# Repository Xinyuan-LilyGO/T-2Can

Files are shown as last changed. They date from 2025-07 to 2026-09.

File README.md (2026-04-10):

<!--
 * @Description: None
 * @Author: LILYGO_L
 * @Date: 2023-09-11 16:13:14
 * @LastEditTime: 2026-04-10 15:54:21
 * @License: GPL 3.0
-->
<h1 align = "center">T-2Can</h1>

## **English | [中文](./README_CN.md)**

## VersionIteration:
| Version | Update date |Update description|
| :---: | :---: |:---: |
| T-2Can_V1.0 | 2025-07-07 | Original version |
| T-2Can-Fd_V1.0 | 2026-04-10 | Can fd version |

## PurchaseLink

| Product | SOC |  FLASH  |  PSRAM | Link |
| :---: | :---: |:---: | :---: | :---: |
| T-2Can_V1.0 | NULL | NULL | NULL |  [LILYGO Mall](https://lilygo.cc/products/t-2can?_pos=1&_sid=a2c4b89a1&_ss=r&variant=51355687583925) |
| T-2Can-Fd_V1.0 | NULL | NULL | NULL |  [NULL]() |

## Directory
- [Describe](#describe)
- [Preview](#preview)
- [Module](#module)
- [SoftwareDeployment](#SoftwareDeployment)
- [PinOverview](#pinoverview)
- [RelatedTests](#RelatedTests)
- [FAQ](#faq)
- [Project](#project)

## Describe

The T-2Can is a board developed based on the ESP32-S3 chip and features two CAN buses. The T-2Can-Fd is the FD version of the T-2Can, adding CAN FD functionality. The CAN module used on the T-2Can is the MCP2515, while the CAN module used on the T-2Can-Fd is the MCP2518.

## Preview

### Actual Product Image

## Module

### 1. Core Processor  

* Module: ESP32-S3-WROOM-1U（MCN16R8）
* Related documentation: 
    >[Espressif](https://www.espressif.com/en/support/documents/technical-documents)
    
### 2. CAN chip

> #### T-2Can_V1.0 version
> * Chip: MCP2515
> * Communication Protocol: Spi
> * Related documentation: 
>    >[MCP2515T-E-SO](./information/MCP2515T-E-SO.pdf)
> * Dependent libraries: 
>    >[arduino-mcp2515](https://github.com/autowp/arduino-mcp2515)

> #### T-2Can-Fd_V1.0 version
> * Chip: MCP2518
> * Communication Protocol: Spi
> * Related documentation: 
>    >[MCP2518FDT-E-SL](./information/MCP2518FDT-E-SL.pdf)
> * Dependent libraries: 
>    >[Longan_CANFD](https://github.com/Longan-Labs/Longan_CANFD)

## SoftwareDeployment

### Examples Support

| Example | `[Platformio IDE][espressif32-v6.5.0]`<br />`[Arduino IDE][esp32_v2.0.14]` | Description | Picture |
| ---  | --- | --- | --- |
| [can](./examples/can) |  <p align="center"> | | |
| [original_test](./examples/original_test) |  <p align="center"> | factory example | |

[supported]: https://img.shields.io/badge/-supported-green "example"

| Firmware | Description | Picture |
| ---  | ---  | --- |
| [original_test](./firmware/[T-2Can_V1.0][original_test]_firmware/) | factory example  |  |
| [original_test (can fd)](./firmware/[T-2Can-Fd_V1.0][original_test]_firmware/) | can fd factory example  |  |

### PlatformIO
1. Install [VisualStudioCode](https://code.visualstudio.com/Download) ,Choose installation based on your system type.

2. Open the "Extension" section of the Visual Studio Code software sidebar(Alternatively, use "<kbd>Ctrl</kbd>+<kbd>Shift</kbd>+<kbd>X</kbd>" to open the extension),Search for the "PlatformIO IDE" extension and download it.

3. During the installation of the extension, you can go to GitHub to download the program. You can download the main branch by clicking on the "<> Code" with green text, or you can download the program versions from the "Releases" section in the sidebar.

4. After the installation of the extension is completed, open the Explorer in the sidebar(Alternatively, use "<kbd>Ctrl</kbd>+<kbd>Shift</kbd>+<kbd>E</kbd>" go open it),Click on "Open Folder," locate the project code you just downloaded (the entire folder), and click "Add." At this point, the project files will be added to your workspace.

5. Open the "platformio.ini" file in the project folder (PlatformIO will automatically open the "platformio.ini" file corresponding to the added folder). Under the "[platformio]" section, uncomment and select the example program you want to burn (it should start with "default_envs = xxx") Then click "<kbd>[√](image/4.png)</kbd>" in the bottom left corner to compile,If the compilation is correct, connect the microcontroller to the computer and click "<kbd>[→](image/5.png)</kbd>" in the bottom left corner to download the program.

### Arduino
1. Install [Arduino](https://www.arduino.cc/en/software) ,Choose installation based on your system type.

2. Open the "example" directory within the project folder, select the example project folder, and open the file ending with ".ino" to open the Arduino IDE project workspace.

3. Open the "Tools" menu at the top right -> Select "Board" -> "Board Manager." Find or search for "esp32" and download the board files from the author named "Espressif Systems." Then, go back to the "Board" menu and select the development board type under "ESP32 Arduino." The selected development board type should match the one specified in the "platformio.ini" file under the [env] section with the header "board = xxx." If there is no corresponding development board, you may need to manually add the development board from the "board" directory within your project folder.

4. Open menu bar "[File](image/6.png)" -> "[Preferences](image/6.png)" ,Find "[Sketchbook location](image/7.png)"  here,copy and paste all library files and folders from the "libraries" folder in the project directory into the "libraries" folder in this directory.

5. Select the correct settings in the Tools menu, as shown in the table below.

#### ESP32-S3
| Setting | Value |
| :---: | :---: |
| Board | ESP32S3 Dev Module |
| Upload Speed | 921600 |
| USB Mode | Hardware CDC and JTAG |
| USB CDC On Boot | Enabled |
| USB Firmware MSC On Boot | Disabled |
| USB DFU On Boot | Disabled |
| CPU Frequency | 240MHz (WiFi) |
| Flash Mode | QIO 80MHz |
| Flash Size | 16MB (128Mb) |
| Core Debug Level | None |
| Partition Scheme | 16M Flash (3MB APP/9.9MB FATFS) |
| PSRAM | OPI PSRAM |
| Arduino Runs On | Core 1 |
| Events Run On | Core 1 | 

6. Select the correct port.

7. Click "<kbd>[√](image/8.png)</kbd>" in the upper right corner to compile,If the compilation is correct, connect the microcontroller to the computer,Click "<kbd>[→](image/9.png)</kbd>" in the upper right corner to download.

### firmware download
1. Open the project file "tools" and locate the ESP32 burning tool. Open it.

2. Select the correct burning chip and burning method, then click "OK." As shown in the picture, follow steps 1->2->3->4->5 to burn the program. If the burning is not successful, press and hold the "BOOT-0" button and then download and burn again.

3. Burn the file in the root directory of the project file "[firmware](./firmware/)" file,There is a description of the firmware file version inside, just choose the appropriate version to download.

<p align="center" width="100%">
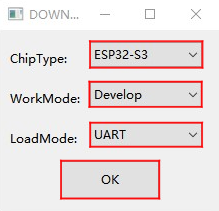
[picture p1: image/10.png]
    
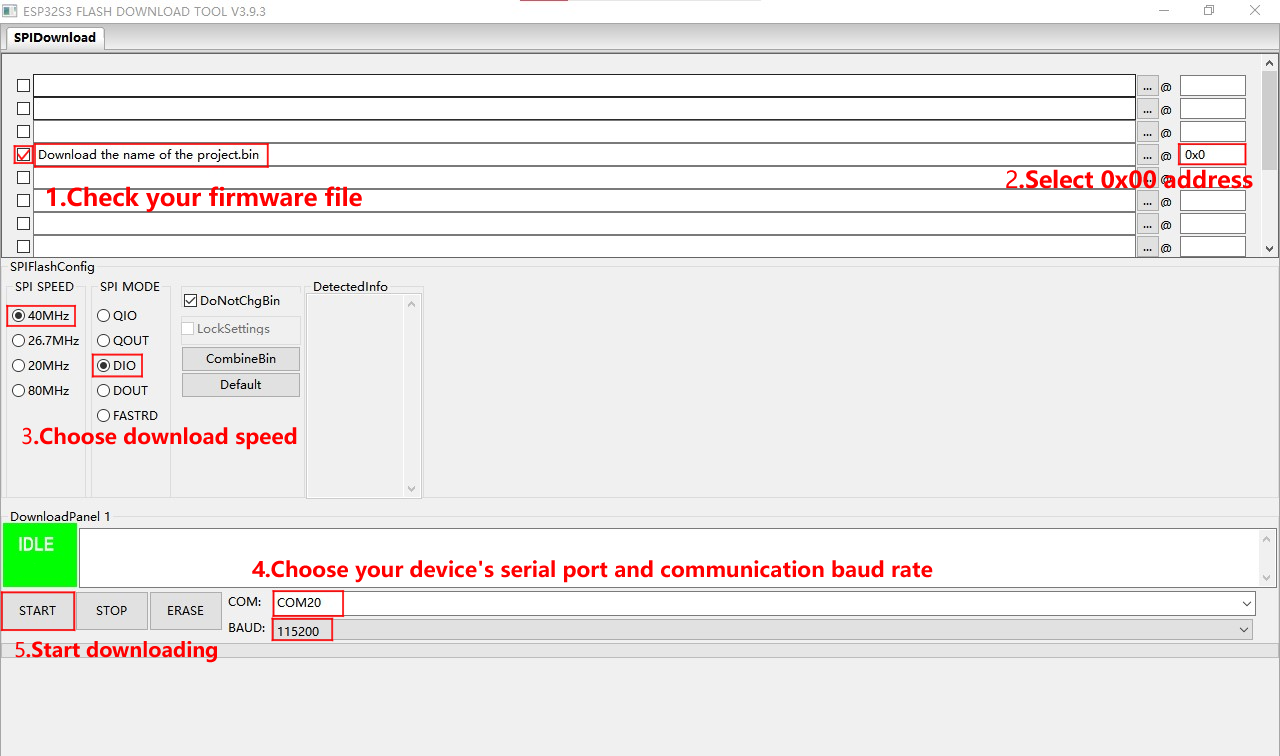
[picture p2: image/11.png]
    
</p>

## PinOverview

For pin definitions, please refer to the configuration file: [pin_config.h](./libraries/private_library/pin_config.h)

## RelatedTests

## FAQ

* Q. After reading the above tutorials, I still don't know how to build a programming environment. What should I do?
* A. If you still don't understand how to build an environment after reading the above tutorials, you can refer to the [LilyGo-Document](https://github.com/Xinyuan-LilyGO/LilyGo-Document) document instructions to build it.

<br />

* Q. Why does Arduino IDE prompt me to update library files when I open it? Should I update them or not?
* A. Choose not to update library files. Different versions of library files may not be mutually compatible, so it is not recommended to update library files.

<br />

* Q. Why is there no serial data output on the "Uart" interface on my board? Is it defective and unusable?
* A. The default project configuration uses the USB interface as Uart0 serial output for debugging purposes. The "Uart" interface is connected to Uart0, so it won't output any data without configuration.<br />For PlatformIO users, please open the project file "platformio.ini" and modify the option under "build_flags = xxx" from "-D ARDUINO_USB_CDC_ON_BOOT=true" to "-D ARDUINO_USB_CDC_ON_BOOT=false" to enable external "Uart" interface.<br />For Arduino users, open the "Tools" menu and select "USB CDC On Boot: Disabled" to enable the external "Uart" interface.

<br />

* Q. Why is my board continuously failing to download the program?
* A. Please hold down the "BOOT-0" button and try downloading the program again.

## Project
* [T-2Can_V1.0](./project/T-2Can_V1.0.pdf)
* [T-2Can-Fd_V1.0](./project/T-2Can-Fd_V1.0.pdf)

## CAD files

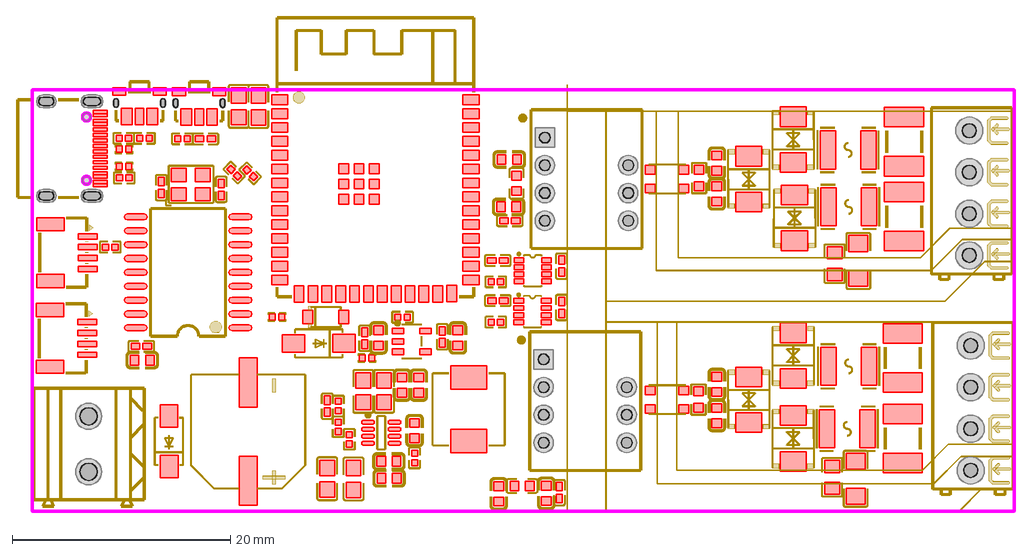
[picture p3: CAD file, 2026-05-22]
structure/T-2Can_Top_AutoCAD2007_202605221644.dxf
91.5 x 45.4 mm

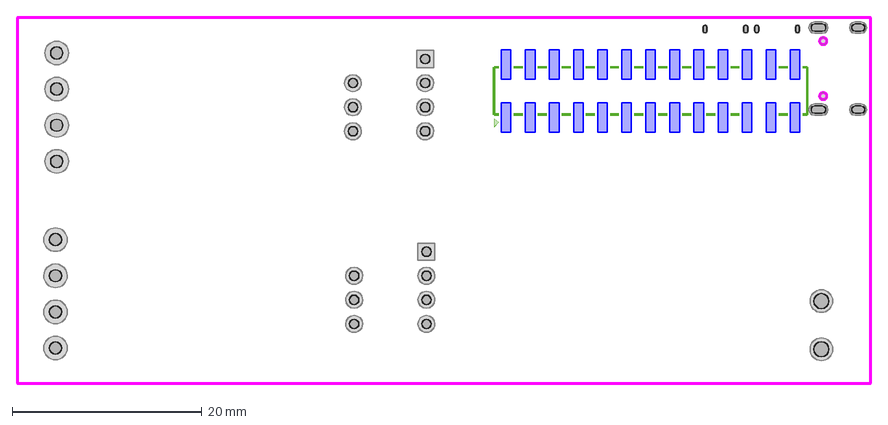
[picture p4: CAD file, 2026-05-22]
structure/T-2Can_Bot_AutoCAD2007_202605221644.dxf
90.2 x 38.8 mm

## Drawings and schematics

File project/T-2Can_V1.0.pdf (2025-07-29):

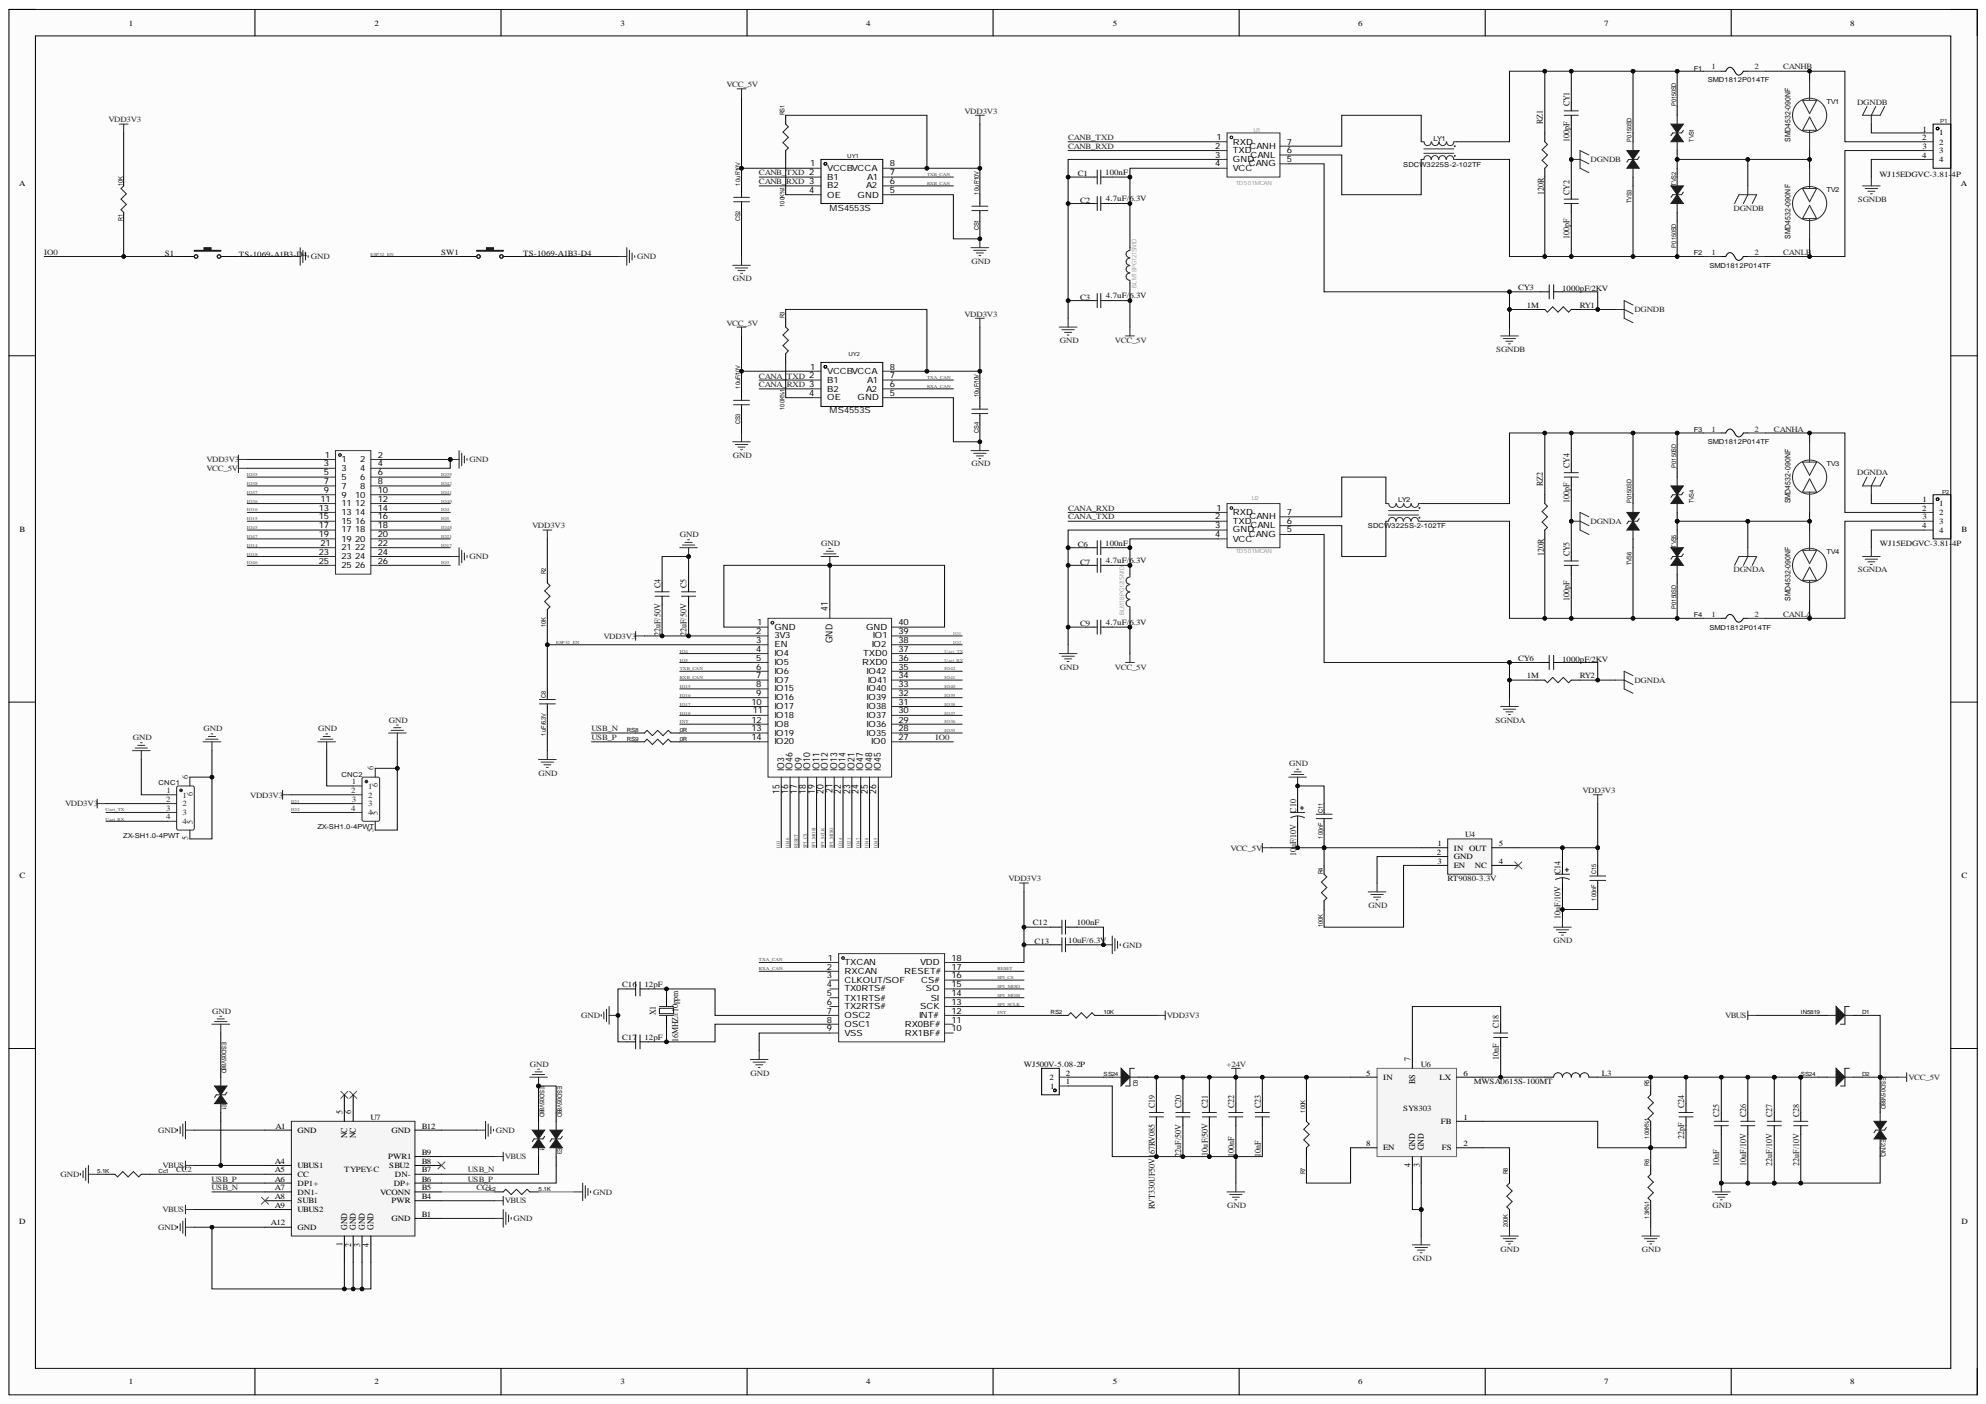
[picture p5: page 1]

C ANA_TXD | | 2 B1 A 1 B2 A 2 O E G N D | 7 T X A_C A N

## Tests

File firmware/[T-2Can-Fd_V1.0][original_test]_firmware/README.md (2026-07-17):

# Firmware Modification Log

## 202607170958
### Changed firmware
- `[T-2Can-Fd_V1.0][original_test]_firmware_202607170958`
### Change content
- 修改串口输出模式为uart

## 202607161625
### Changed firmware
- `[T-2Can-Fd_V1.0][original_test]_firmware_202607161625`
### Change content
- 更新wifi使用两种wifi切换测试

## 202606011018
### Changed firmware
- `[T-2Can-Fd_V1.0][original_test]_firmware_202606011018`
### Change content
- 将wifi下载改为wifi获取实时时间

## 202605281031
### Changed firmware
- `[T-2Can-Fd_V1.0][original_test]_firmware_202605281031`
### Change content
- 将串口日志输出修改为uart0

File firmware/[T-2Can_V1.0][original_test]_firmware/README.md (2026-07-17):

# Firmware Modification Log

## 202607170958
### Changed firmware
- `[T-2Can_V1.0][original_test]_firmware_202607170958`
### Change content
- 修改串口输出模式为uart

## 202607161625
### Changed firmware
- `[T-2Can_V1.0][original_test]_firmware_202607161625`
### Change content
- 更新wifi使用两种wifi切换测试

## 202606011019
### Changed firmware
- `[T-2Can_V1.0][original_test]_firmware_202606011019`
### Change content
- 将wifi下载改为wifi获取实时时间

## 202605281024
### Changed firmware
- `[T-2Can_V1.0][original_test]_firmware_202605281024`
### Change content
- 将串口日志输出修改为uart0

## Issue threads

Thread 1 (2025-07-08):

Why one CAN native ESP32, the other via the MCP2515 over SPI?

Bwooce, 2025-07-08:
### What features or library support or other would you like to add?

Can you explain the design rationale? Have you found the two-can-bus support in the ESP32-S3 to be unreliable/overloads the chip if both are used simultaneously, or are there other benefits to having the one of the CAN interfaces offloaded like this?

(I've just bought 2x T-Connects, which I just worked out can only have max two of the four interfaces live at any one time, but even two will need to use both CAN1 and CAN2 on the ESP32-S3 so I am interested if I should swap to this board instead.)

### Additional context.

_No response_

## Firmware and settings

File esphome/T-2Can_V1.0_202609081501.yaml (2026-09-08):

# 已验证版本：ESPHome 2026.8.2。
# GPIO 初始化后，先将 MCP2515 RESET 拉低 10ms，再拉高并等待 10ms，最后初始化 CAN。
esphome:
  name: t-2can-v1-0-202609081501
  friendly_name: "T-2Can_V1.0_202609081501"
  on_boot:
    priority: 700.0
    then:
      # 使用同步延时，确保复位完成后再初始化 CAN。
      - lambda: |-
          ESP_LOGI("mcp_reset", "Resetting MCP2515 before CAN setup");
          id(mcp_rst_pin).turn_off();
          esphome::delay(10);
          id(mcp_rst_pin).turn_on();
          esphome::delay(10);
          ESP_LOGI("mcp_reset", "MCP2515 reset released");

esp32:
  board: esp32-s3-devkitm-1
  framework:
    type: esp-idf

# Enable logging
logger:

api:
  port: 6053
  batch_delay: 50ms  # Reduce latency for real-time applications
  listen_backlog: 2  # Allow 2 pending connections in queue
  max_connections: 6  # Allow up to 6 simultaneous connections
  max_send_queue: 10  # Maximum queued messages per connection before disconnect

wifi:
  ssid: LilyGo-AABB
  password: xinyuandianzi

# 定义复位引脚输出
output:
  - platform: gpio
    pin: GPIO9
    id: mcp_rst_pin

# SPI 配置 (MCP2515 使用)
spi:
  clk_pin: GPIO12
  mosi_pin: GPIO11
  miso_pin: GPIO13

canbus:
  # 1. ESP32-S3 内置 CAN (TWAI)
  - platform: esp32_can
    id: internal_can
    tx_pin: GPIO7
    rx_pin: GPIO6
    can_id: 0x100
    bit_rate: 250kbps
    on_frame:
      - can_id: 0x200 # 监听来自 MCP2515 的数据
        then:
          - lambda: |-
              id(rx_display_internal).publish_state("From MCP: " + format_hex_pretty(x));
              ESP_LOGI("CAN", "Internal CAN receive: %s", format_hex_pretty(x).c_str());

  # 2. MCP2515 外置 CAN
  - platform: mcp2515
    setup_priority: -100.0
    id: external_can
    cs_pin: GPIO10
    can_id: 0x200
    bit_rate: 250kbps
    clock: 16MHz
    mode: NORMAL
    on_frame:
      - can_id: 0x100 # 监听来自 Internal CAN 的数据
        then:
          - lambda: |-
              id(rx_display_mcp).publish_state("From Internal: " + format_hex_pretty(x));
              ESP_LOGI("CAN", "MCP2515 receive: %s", format_hex_pretty(x).c_str());

# 控制按钮：用于触发发送
button:
  - platform: template
    name: "Send: Internal -> MCP"
    icon: "mdi:arrow-right-bold"
    on_press:
      - canbus.send:
          canbus_id: internal_can
          can_id: 0x100
          data: [0x01, 0x02, 0x03, 0x04, 0x05, 0x06, 0x07, 0x08]

  - platform: template
    name: "Send: MCP -> Internal"
    icon: "mdi:arrow-left-bold"
    on_press:
      - canbus.send:
          canbus_id: external_can
          can_id: 0x200
          data: [0x08, 0x07, 0x06, 0x05, 0x04, 0x03, 0x02, 0x01]

# 状态显示：在 Home Assistant Dashboard 查看结果
text_sensor:
  - platform: template
    name: "Internal CAN Rx Status"
    id: rx_display_internal
  - platform: template
    name: "MCP2515 Rx Status"
    id: rx_display_mcp

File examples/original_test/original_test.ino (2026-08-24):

/*
 * @Description: original_test
 * @Author: LILYGO_L
 * @Date: 2024-11-07 10:04:14
 * @LastEditTime: 2026-07-16 16:04:39
 * @License: GPL 3.0
 */

#include <Arduino.h>
#include <stdarg.h>
#include "driver/twai.h"
#include "pin_config.h"
#if defined T_2Can
#include "mcp2515.h"
#elif defined T_2Can_Fd
#include "mcp2518fd_can.h"
#else
#error "no macro definition is set"
#endif
#include <SPI.h>
#include "WiFi.h"
#include <WebServer.h>
#include <esp_mac.h>
#include <time.h>

// Intervall:
#define POLLING_RATE_MS 100

#define WIFI_SSID_1 "LilyGo-AABB"
#define WIFI_PASSWORD_1 "xinyuandianzi"
#define WIFI_SSID_2 "xinyuandianzi"
#define WIFI_PASSWORD_2 "AA15994823428"

#define WIFI_CONNECT_WAIT_MAX 40000UL
#define WIFI_NETWORK_SWITCH_INTERVAL 10000UL
#define WIFI_CONNECT_POLL_INTERVAL 50UL
#define WIFI_CONNECT_LOG_INTERVAL 500UL
#define WIFI_TIME_SYNC_WAIT_MAX 40000UL
#define WIFI_TIME_SYNC_POLL_TIMEOUT 500UL
#define WIFI_TIME_ZONE_OFFSET_SEC (8 * 60 * 60)
#define WIFI_DAYLIGHT_OFFSET_SEC 0
#define WIFI_AP_SSID_PREFIX "T-2Can_"
#define WIFI_AP_PASSWORD "12345678"
#define WIFI_AP_CHANNEL 1
#define WIFI_AP_MAX_CONNECTIONS 4
#define WEB_LOG_MAX_LENGTH 20000

#if defined T_2Can
#elif defined T_2Can_Fd
#define MAX_DATA_SIZE 64
#else
#error "no macro definition is set"
#endif

#define SOFTWARE_NAME "Original_Test"
#define SOFTWARE_LASTEDITTIME "202607161604"
#define BOARD_VERSION "V1.0"

size_t CycleTime = 0;

uint64_t Can_Count = 0;

bool Can_A_B_Send_Flag = true;

static bool Wifi_Connection_Flag = false;
static bool Wifi_AP_Flag = false;
static char Wifi_AP_SSID[sizeof(WIFI_AP_SSID_PREFIX) + 12];
static String Web_Log_Buffer;
WebServer Http_Server(80);

struct WifiNetworkCredential
{
    const char *ssid;
    const char *password;
};

static const WifiNetworkCredential Wifi_Networks[] = {
    {WIFI_SSID_1, WIFI_PASSWORD_1},
    {WIFI_SSID_2, WIFI_PASSWORD_2},
};

static const size_t WIFI_NETWORK_COUNT = sizeof(Wifi_Networks) / sizeof(Wifi_Networks[0]);

void AppLogPrint(const String &message);
template <typename T>
void AppLogPrint(const T &message);
void AppLogPrintln(const String &message = "");
template <typename T>
void AppLogPrintln(const T &message);
void AppLogPrintf(const char *format, ...);

#if defined T_2Can
struct can_frame Can_Receive_Package;
struct can_frame Can_Send_Package;

MCP2515 Can_A(MCP2515_CS, 10000000, &SPI);
#elif defined T_2Can_Fd
uint8_t Can_Receive_Package[MAX_DATA_SIZE];
uint8_t Can_Send_Package[MAX_DATA_SIZE];

mcp2518fd Can_A(MCP2518_CS);
#else
#error "no macro definition is set"
#endif

void AppendWebLog(const String &message)
{
    Web_Log_Buffer += message;
    if (Web_Log_Buffer.length() > WEB_LOG_MAX_LENGTH)
    {
        Web_Log_Buffer.remove(0, Web_Log_Buffer.length() - WEB_LOG_MAX_LENGTH);
    }
}

void AppLogPrint(const String &message)
{
    Serial.print(message);
    AppendWebLog(message);
}

template <typename T>
void AppLogPrint(const T &message)
{
    Serial.print(message);
    AppendWebLog(String(message));
}

void AppLogPrintln(const String &message)
{
    Serial.println(message);
    AppendWebLog(message + "\n");
}

template <typename T>
void AppLogPrintln(const T &message)
{
    Serial.println(message);
    AppendWebLog(String(message) + "\n");
}

void AppLogPrintf(const char *format, ...)
{
    char buffer[256];
    va_list args;
    va_start(args, format);
    int length = vsnprintf(buffer, sizeof(buffer), format, args);
    va_end(args);

    if (length < 0)
    {
        return;
    }

    if ((size_t)length < sizeof(buffer))
    {
        AppLogPrint(String(buffer));
        return;
    }

    char *dynamic_buffer = (char *)malloc(length + 1);
    if (dynamic_buffer == NULL)
    {
        AppLogPrint(String(buffer));
        return;
    }

    va_start(args, format);
    vsnprintf(dynamic_buffer, length + 1, format, args);
    va_end(args);
    AppLogPrint(String(dynamic_buffer));
    free(dynamic_buffer);
}

String HtmlEscape(const String &input)
{
    String output;
    output.reserve(input.length());
    for (size_t i = 0; i < input.length(); i++)
    {
        char c = input[i];
        if (c == '&')
        {
            output += "&amp;";
        }
        else if (c == '<')
        {
            output += "&lt;";
        }
        else if (c == '>')
        {
            output += "&gt;";
        }
        else
        {
            output += c;
        }
    }
    return output;
}

void HandleRoot()
{
    String html;
    html.reserve(Web_Log_Buffer.length() + 900);
    html += F("<!doctype html><html><head><meta charset='utf-8'>");
    html += F("<meta name='viewport' content='width=device-width,initial-scale=1'>");
    html += F("<title>T-2Can Log</title>");
    html += F("<style>body{font-family:Consolas,monospace;margin:16px;background:#101418;color:#e8eef2;}");
    html += F("a{color:#8cc7ff}pre{white-space:pre-wrap;word-break:break-word;border:1px solid #2d3942;padding:12px;min-height:70vh;background:#05080a;}");
    html += F(".bar{display:flex;gap:12px;align-items:center;margin-bottom:12px}</style>");
    html += F("<script>setInterval(()=>fetch('/log').then(r=>r.text()).then(t=>document.getElementById('log').textContent=t),1000);</script>");
    html += F("</head><body><div class='bar'><strong>T-2Can Serial Log</strong><a href='/log'>text</a><a href='/clear'>clear</a></div><pre id='log'>");
    html += HtmlEscape(Web_Log_Buffer);
    html += F("</pre></body></html>");
    Http_Server.send(200, "text/html; charset=utf-8", html);
}

void HandleLogText()
{
    Http_Server.send(200, "text/plain; charset=utf-8", Web_Log_Buffer);
}

void HandleClearLog()
{
    Web_Log_Buffer = "";
    Http_Server.sendHeader("Location", "/", true);
    Http_Server.send(302, "text/plain", "");
}

void BuildWifiAPSSID(void)
{
    uint8_t factory_mac[6] = {0};
    esp_err_t result = esp_efuse_mac_get_default(factory_mac);
    if (result != ESP_OK)
    {
        AppLogPrintf("Failed to read factory MAC: %d\n", result);
    }

    snprintf(Wifi_AP_SSID, sizeof(Wifi_AP_SSID),
             WIFI_AP_SSID_PREFIX "%02X%02X%02X%02X%02X%02X",
             factory_mac[0], factory_mac[1], factory_mac[2],
             factory_mac[3], factory_mac[4], factory_mac[5]);
}

void Wifi_AP_HTTP_Init(void)
{
    WiFi.persistent(false);
    WiFi.mode(WIFI_AP_STA);
    WiFi.setAutoReconnect(true);
    WiFi.setSleep(false);
    WiFi.setTxPower(WIFI_POWER_19_5dBm);
    WiFi.setMinSecurity(WIFI_AUTH_WPA_PSK);
    WiFi.setScanMethod(WIFI_ALL_CHANNEL_SCAN);
    WiFi.setSortMethod(WIFI_CONNECT_AP_BY_SIGNAL);

    BuildWifiAPSSID();
    Wifi_AP_Flag = WiFi.softAP(Wifi_AP_SSID, WIFI_AP_PASSWORD, WIFI_AP_CHANNEL, false, WIFI_AP_MAX_CONNECTIONS);

    Http_Server.on("/", HTTP_GET, HandleRoot);
    Http_Server.on("/log", HTTP_GET, HandleLogText);
    Http_Server.on("/clear", HTTP_GET, HandleClearLog);
    Http_Server.begin();

    IPAddress ip = WiFi.softAPIP();
    AppLogPrintf("WiFi AP %s\n", Wifi_AP_Flag ? "started" : "start failed");
    AppLogPrintf("AP SSID: %s\n", Wifi_AP_SSID);
    AppLogPrintf("AP password: %s\n", WIFI_AP_PASSWORD);
    AppLogPrintf("HTTP log URL: http://%s/\n", ip.toString().c_str());
}

void Can_B_Drive_Initialization()
{
    // Initialize configuration structures using macro initializers
    twai_general_config_t g_config = TWAI_GENERAL_CONFIG_DEFAULT((gpio_num_t)CAN_TX, (gpio_num_t)CAN_RX, TWAI_MODE_NORMAL);
    twai_timing_config_t t_config = TWAI_TIMING_CONFIG_500KBITS();
    twai_filter_config_t f_config = TWAI_FILTER_CONFIG_ACCEPT_ALL();

    // Install TWAI driver
    if (twai_driver_install(&g_config, &t_config, &f_config) == ESP_OK)
    {
        AppLogPrintln("can b: Driver installed");
    }
    else
    {
        AppLogPrintln("can b: Failed to install driver");
    }

    // Start TWAI driver
    if (twai_start() == ESP_OK)
    {
        AppLogPrintln("can b: Driver started");
    }
    else
    {
        AppLogPrintln("can b: Failed to start driver");
    }

    // 配置
    uint32_t alerts_to_enable = TWAI_ALERT_TX_IDLE | TWAI_ALERT_TX_SUCCESS |
                                TWAI_ALERT_TX_FAILED | TWAI_ALERT_ERR_PASS |
                                TWAI_ALERT_BUS_ERROR | TWAI_ALERT_RX_DATA |
                                TWAI_ALERT_RX_QUEUE_FULL;

    if (twai_reconfigure_alerts(alerts_to_enable, NULL) == ESP_OK)
    {
        AppLogPrintln("can b: CAN Alerts reconfigured");
    }
    else
    {
        AppLogPrintln("can b: Failed to reconfigure alerts");
    }
}

void Can_B_Twai_Send_Message()
{
    // Configure message to transmit
    twai_message_t message;
    message.identifier = 0xBB;
    // message.data_length_code = 1;
    // message.data[0] = Can_Count++;
    message.data_length_code = 8;
    message.data[0] = 1;
    message.data[1] = 2;
    message.data[2] = 3;
    message.data[3] = 4;
    message.data[4] = 5;
    message.data[5] = 6;
    message.data[6] = 7;
    message.data[7] = 8;

    // Queue message for transmission
    if (twai_transmit(&message, pdMS_TO_TICKS(1000)) == ESP_OK)
    {
        // printf("can b: Message queued for transmission\n");
    }
    else
    {
        AppLogPrintf("can b: Failed to queue message for transmission\n");
    }
}

void Can_B_Twai_Receive_Message(twai_message_t &message)
{
    // Process received message
    if (message.extd)
    {
        AppLogPrintln("can b: Message is in Extended Format");
        return;
    }
    else
    {
        // AppLogPrintln("can b: Message is in Standard Format");
    }
    AppLogPrintf("\ncan b received data\n");
    AppLogPrintf("can b receive id: 0x%X\n", message.identifier);
    AppLogPrintf("can b receive data length: %d\n", message.data_length_code);
    if (!(message.rtr))
    {
        for (int i = 0; i < message.data_length_code; i++)
        {
            AppLogPrintf("can b receive data [%d]: %d\n", i, message.data[i]);
        }
        AppLogPrintln("");
    }
}

void Wifi_STA_Test(void)
{
    String text;
    int wifi_num = 0;

    AppLogPrintf("\nScanning wifi");
    WiFi.mode(WIFI_AP_STA);
    delay(100);

    wifi_num = WiFi.scanNetworks();
    if (wifi_num == 0)
    {
        text = "\nWiFi scan complete !\nNo wifi discovered.\n";
    }
    else
    {
        text = "\nWiFi scan complete !\n";
        text += wifi_num;
        text += " wifi discovered.\n\n";

        for (int i = 0; i < wifi_num; i++)
        {
            text += (i + 1);
            text += ": ";
            text += WiFi.SSID(i);
            text += " (";
            text += WiFi.RSSI(i);
            text += ")";
            text += (WiFi.encryptionType(i) == WIFI_AUTH_OPEN) ? " \n" : "*\n";
            delay(10);
        }
    }

    AppLogPrintln(text);
    WiFi.scanDelete();

    size_t network_index = 0;
    uint32_t start_tick = millis();
    uint32_t next_switch_tick = WIFI_NETWORK_SWITCH_INTERVAL;
    uint32_t last_log_tick = start_tick;

    Wifi_Connection_Flag = false;
    AppLogPrintf("Connecting to %s", Wifi_Networks[network_index].ssid);
    WiFi.begin(Wifi_Networks[network_index].ssid, Wifi_Networks[network_index].password);

    while (WiFi.status() != WL_CONNECTED)
    {
        Http_Server.handleClient();
        uint32_t now = millis();
        uint32_t elapsed = now - start_tick;

        if (elapsed >= WIFI_CONNECT_WAIT_MAX)
        {
            break;
        }

        if (elapsed >= next_switch_tick)
        {
            network_index = (network_index + 1) % WIFI_NETWORK_COUNT;
            AppLogPrintf("\nSwitching to %s", Wifi_Networks[network_index].ssid);
            WiFi.begin(Wifi_Networks[network_index].ssid, Wifi_Networks[network_index].password);
            next_switch_tick += WIFI_NETWORK_SWITCH_INTERVAL;
            last_log_tick = now;
        }

        if (now - last_log_tick >= WIFI_CONNECT_LOG_INTERVAL)
        {
            AppLogPrint(".");
            last_log_tick = now;
        }

        delay(WIFI_CONNECT_POLL_INTERVAL);
    }

    Wifi_Connection_Flag = (WiFi.status() == WL_CONNECTED);

    if (Wifi_Connection_Flag == true)
    {
        AppLogPrint("\nThe connection was successful ! \nTakes ");
        AppLogPrint(millis() - start_tick);
        AppLogPrintln(" ms\n");
        AppLogPrintf("Connected SSID: %s\n", WiFi.SSID().c_str());
        AppLogPrintf("STA IP: %s\n", WiFi.localIP().toString().c_str());
        AppLogPrintf("RSSI: %d dBm\n", WiFi.RSSI());
    }
    else
    {
        AppLogPrintf("\nWifi test error after %lu ms (status: %d)\n",
                     millis() - start_tick, WiFi.status());
    }
}

void WIFI_Time_Test(void)
{
    if (Wifi_Connection_Flag != true)
    {
        AppLogPrintln("Not connected to the network");
        return;
    }

    AppLogPrintln("Syncing time from NTP...");
    configTime(WIFI_TIME_ZONE_OFFSET_SEC, WIFI_DAYLIGHT_OFFSET_SEC,
               "pool.ntp.org", "time.nist.gov", "ntp.aliyun.com");

    struct tm timeinfo = {};
    uint32_t start_tick = millis();
    bool time_sync_success = false;

    while (millis() - start_tick < WIFI_TIME_SYNC_WAIT_MAX)
    {
        uint32_t elapsed = millis() - start_tick;
        uint32_t remaining = WIFI_TIME_SYNC_WAIT_MAX - elapsed;
        uint32_t poll_timeout = remaining < WIFI_TIME_SYNC_POLL_TIMEOUT
                                    ? remaining
                                    : WIFI_TIME_SYNC_POLL_TIMEOUT;

        if (getLocalTime(&timeinfo, poll_timeout))
        {
            time_sync_success = true;
            break;
        }

        Http_Server.handleClient();
        AppLogPrint(".");
    }

    if (!time_sync_success)
    {
        AppLogPrintf("\nNTP time sync failed after %lu ms\n", millis() - start_tick);
        return;
    }

    AppLogPrintln();
    AppLogPrintf("NTP time sync success, takes %lu ms\n", millis() - start_tick);
    AppLogPrintf("Local time: %04d-%02d-%02d %02d:%02d:%02d\n",
                  timeinfo.tm_year + 1900,
                  timeinfo.tm_mon + 1,
                  timeinfo.tm_mday,
                  timeinfo.tm_hour,
                  timeinfo.tm_min,
                  timeinfo.tm_sec);
}

void setup()
{
    Serial.begin(115200);
    AppLogPrintln("Ciallo");
#if defined T_2Can
    AppLogPrintln("[T_2Can_" + (String)BOARD_VERSION "][" + (String)SOFTWARE_NAME +
                   "]_firmware_" + (String)SOFTWARE_LASTEDITTIME);

#elif defined T_2Can_Fd
    AppLogPrintln("[T_2Can_Fd_" + (String)BOARD_VERSION "][" + (String)SOFTWARE_NAME +
                   "]_firmware_" + (String)SOFTWARE_LASTEDITTIME);
#else
#error "no macro definition is set"
#endif

    Wifi_AP_HTTP_Init();
    Wifi_STA_Test();
    WIFI_Time_Test();

#if defined T_2Can
    Can_Send_Package.can_id = 0xAA;
    Can_Send_Package.can_dlc = 8;
    Can_Send_Package.data[0] = 8;
    Can_Send_Package.data[1] = 7;
    Can_Send_Package.data[2] = 6;
    Can_Send_Package.data[3] = 5;
    Can_Send_Package.data[4] = 4;
    Can_Send_Package.data[5] = 3;
    Can_Send_Package.data[6] = 2;
    Can_Send_Package.data[7] = 1;

    pinMode(MCP2515_RST, OUTPUT);
    digitalWrite(MCP2515_RST, HIGH);
    delay(100);
    digitalWrite(MCP2515_RST, LOW);
    delay(100);
    digitalWrite(MCP2515_RST, HIGH);
    delay(100);

    SPI.begin(MCP2515_SCLK, MCP2515_MISO, MCP2515_MOSI, MCP2515_CS); // SPI boots

    Can_A.reset();
    Can_A.setBitrate(CAN_500KBPS);
    Can_A.setNormalMode();

    AppLogPrintln("can a speed: 500kbps");

#elif defined T_2Can_Fd
    memset(Can_Send_Package, 'A', MAX_DATA_SIZE);

    Can_A.setMode(CAN_NORMAL_MODE);

    SPI.begin(MCP2518_SCLK, MCP2518_MISO, MCP2518_MOSI, MCP2518_CS); // SPI boots

    if (Can_A.begin(CAN_500K_5M) != CAN_OK)
    {
        AppLogPrintln("can a fd init fail");
    }
    else
    {
        AppLogPrintln("can a fd init success");
    }

    AppLogPrintln("can a fd speed: 5000kbps");
#else
#error "no macro definition is set"
#endif

    Can_B_Drive_Initialization();
    AppLogPrintln("can b speed: 500kbps");
}

void loop()
{
    Http_Server.handleClient();

    // 通信报警检测
    uint32_t alerts_triggered;
    twai_read_alerts(&alerts_triggered, pdMS_TO_TICKS(POLLING_RATE_MS));
    // 总线状态信息
    // twai_status_info_t twai_status_info;
    // twai_get_status_info(&twai_status_info);

    // switch (alerts_triggered)
    // {
    // case TWAI_ALERT_ERR_PASS:
    //     AppLogPrintln("\ncan b: Alert: TWAI controller has become error passive.");
    //     delay(1000);
    //     break;
    // case TWAI_ALERT_BUS_ERROR:
    // {
    //     AppLogPrintln("\ncan b: Alert: A (Bit, Stuff, CRC, Form, ACK) error has occurred on the bus.");
    //     AppLogPrintf("can b: Bus error count: %d\n", twai_status_info.bus_error_count);

    //     uint8_t temp = 0;
    //     while (1)
    //     {
    //         uint32_t alerts_triggered;
    //         twai_read_alerts(&alerts_triggered, pdMS_TO_TICKS(POLLING_RATE_MS));
    //         // 总线状态信息
    //         twai_status_info_t twai_status_info;
    //         twai_get_status_info(&twai_status_info);

    //         temp++;
    //         if (temp > 3)
    //         {
    //             break;
    //         }

    //         delay(1000);
    //     }
    // }
    // break;
    // case TWAI_ALERT_TX_FAILED:
    //     AppLogPrintln("\ncan b: Alert: The Transmission failed.");
    //     AppLogPrintf("can b: TX buffered: %d\n", twai_status_info.msgs_to_tx);
    //     AppLogPrintf("can b: TX error: %d\n", twai_status_info.tx_error_counter);
    //     AppLogPrintf("can b: TX failed: %d\n", twai_status_info.tx_failed_count);
    //     delay(1000);
    //     break;
    // case TWAI_ALERT_TX_SUCCESS:
    //     AppLogPrintln("\ncan b: Alert: The Transmission was successful.");
    //     AppLogPrintf("can b: TX buffered: %d\n", twai_status_info.msgs_to_tx);
    //     break;
    // case TWAI_ALERT_RX_QUEUE_FULL:
    //     AppLogPrintln("\ncan b: Alert: The RX queue is full causing a received frame to be lost.");
    //     AppLogPrintf("can b: RX buffered: %d\n", twai_status_info.msgs_to_rx);
    //     AppLogPrintf("can b: RX missed: %d\n", twai_status_info.rx_missed_count);
    //     AppLogPrintf("can b: RX overrun %d\n", twai_status_info.rx_overrun_count);

    //     twai_clear_receive_queue();
    //     delay(1000);
    //     break;

    // default:
    //     break;
    // }

    // switch (twai_status_info.state)
    // {
    // case TWAI_STATE_RUNNING:
    //     AppLogPrintln("\ncan b: TWAI_STATE_RUNNING");
    //     break;
    // case TWAI_STATE_BUS_OFF:
    //     AppLogPrintln("\ncan b: TWAI_STATE_BUS_OFF");
    //     twai_initiate_recovery();
    //     // delay(1000);
    //     break;
    // case TWAI_STATE_STOPPED:
    //     AppLogPrintln("\ncan b: TWAI_STATE_STOPPED");
    //     twai_start();
    //     delay(1000);
    //     break;
    // case TWAI_STATE_RECOVERING:
    //     AppLogPrintln("\ncan b: TWAI_STATE_RECOVERING");
    //     delay(1000);
    //     break;

    // default:
    //     break;
    // }

    // 如果TWAI有信息接收到
    if (alerts_triggered & TWAI_ALERT_RX_DATA)
    {
        twai_message_t rx_buf;

        while (twai_receive(&rx_buf, 0) == ESP_OK)
        {
            Can_B_Twai_Receive_Message(rx_buf);
            delay(10);
        }
    }

    if (millis() > CycleTime)
    {
        if (Can_A_B_Send_Flag == true)
        {
#if defined T_2Can
            AppLogPrintf("can a: send data\n");
            Can_A.sendMessage(&Can_Send_Package);
#elif defined T_2Can_Fd
            AppLogPrintf("can a fd: send data\n");
            Can_A.sendMsgBuf(0xAA, 0, CANFD::len2dlc(MAX_DATA_SIZE), Can_Send_Package);
#else
#error "no macro definition is set"
#endif

        }
        else
        {
            AppLogPrintf("can b: send data\n");
            Can_B_Twai_Send_Message();
        }
        Can_A_B_Send_Flag = !Can_A_B_Send_Flag;

        CycleTime = millis() + 3000;
    }
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

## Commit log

2025-12-15 update structure #8
    [T-2Can_Bot_AutoCAD2007.dxf, T-2Can_Top_AutoCAD2007.dxf]
2026-05-22 update structure
    [T-2Can_Bot_AutoCAD2007.dxf, T-2Can_Bot_AutoCAD2007_202605221644.dxf, T-2Can_Top_AutoCAD2007.dxf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]
2026-06-12 Update esp32_can
2026-07-16 Update WiFi to support switching between two WiFi networks for testing.
2026-07-17 Modify the serial output mode to UART.
2026-08-24 fix(original_test): correct CAN A bitrate log #13
    -update the CAN A speed log from 1000 kbps to 500 kbps to match the configured CAN_500KBPS bitrate.
    [original_test.ino]
2026-09-08 fix(esphome): correct T-2Can MCP2515 reset timing
    - complete the hardware reset synchronously after GPIO initialization
    - rename the configuration to T-2Can_V1.0_202609081501.yaml
    [T-2Can_V1.0_202609081501.yaml]
2026-09-08 fix(esphome): correct T-2Can MCP2515 reset timing (#11)
    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
    [T-2Can_V1.0_202609081501.yaml]
2026-10-22 feat(examples): add CAN controller startup diagnostics
    - Add MCP2515 reset, SPI communication, bitrate and mode status logs.
    - Add MCP2518FD register readback and initialization status logs.
    - Keep setup running when an initialization check fails.
    - Correct CAN bitrate log messages.
